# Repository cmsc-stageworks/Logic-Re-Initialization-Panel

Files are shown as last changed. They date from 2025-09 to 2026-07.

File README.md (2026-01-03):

# Logic Initialization Panel

Created by the BYU IEEE Branch for the CMSC

## Overview
The idea is that you take an isolinear chip that is "broken" and you place it in to have a certain logic circuit "fixed/repaired" the screen gives you a guide to be able to solve the puzzle/prompt. you then "write" it to the card

### Puzzle setup
The puzzle would consist of a series of (up to) 4 inputs and (up to) 4 outputs. These inputs could be things such as "Engine overheating" or "Autorization level 4 is given" or "Fire detected". The outputs could be "Turn on cooling fans" or "Override safety protocols" or "open airlock" etc. The user would be responsible for implemmenting the logic necessary to solve the puzzle at hand. 

### Interactivity
The user can test inputs manually by pressing the 4 buttons off to the input side of the logic panel, turning them on or off (true or false). They can then visually see how the logic would travel step by step in their current circuit.

### Completion
When they are ready to submit they hit the write button and it tests their circuit to verify correctness. If it is incorrect it throws an error and lets them try again. If it is correct it "writes" it to the card and they can move the card back to its original position to "fix" or "optimize" a system

## Learning outcomes
This panel teaches basic boolean logic (not, and, or) to children, or can be configured to challenge adults with more gates/configurations.

### Gate holder
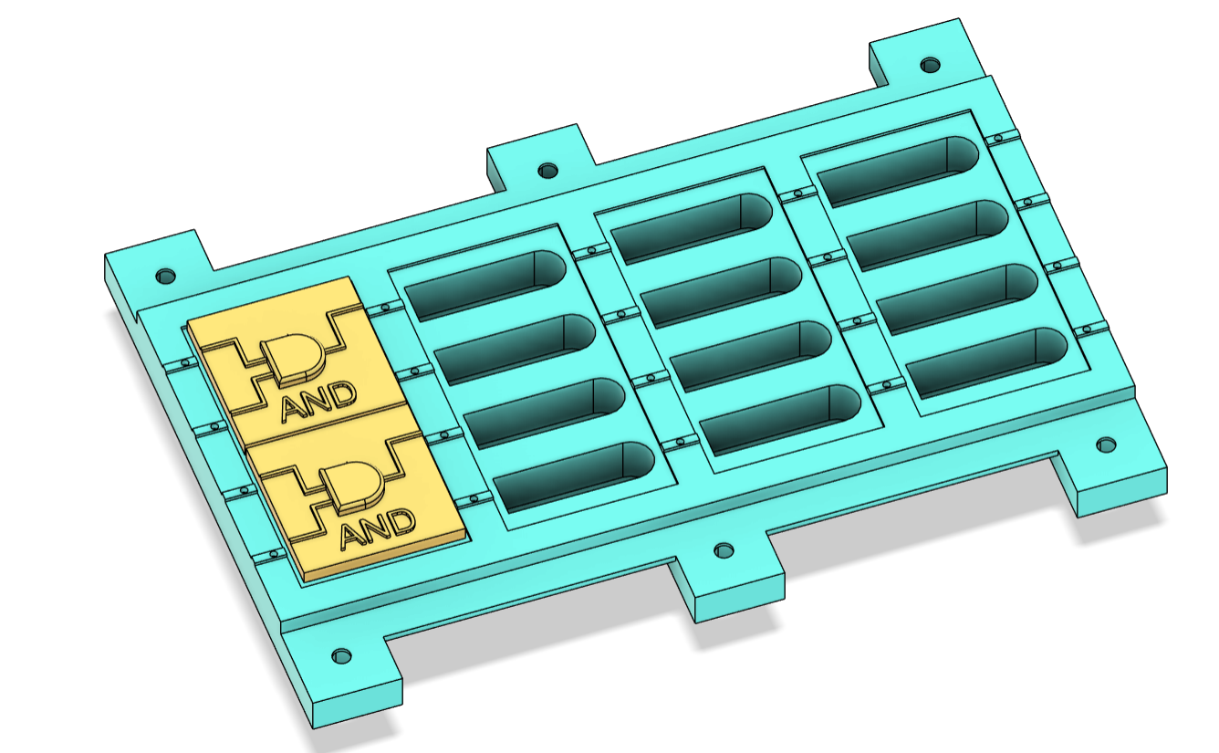
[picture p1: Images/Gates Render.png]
3d Render

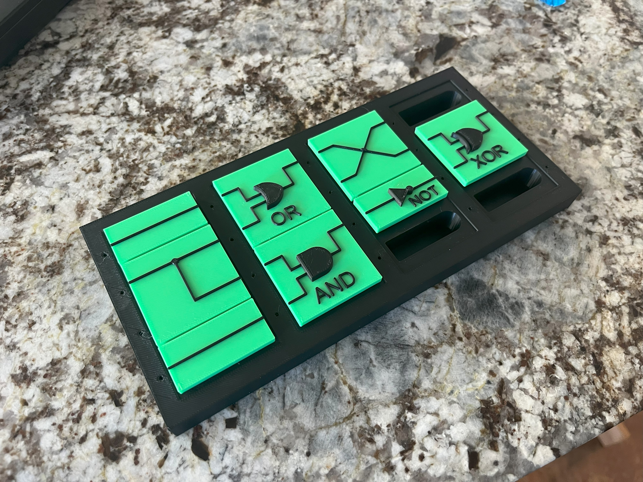
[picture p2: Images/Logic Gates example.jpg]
Example 1

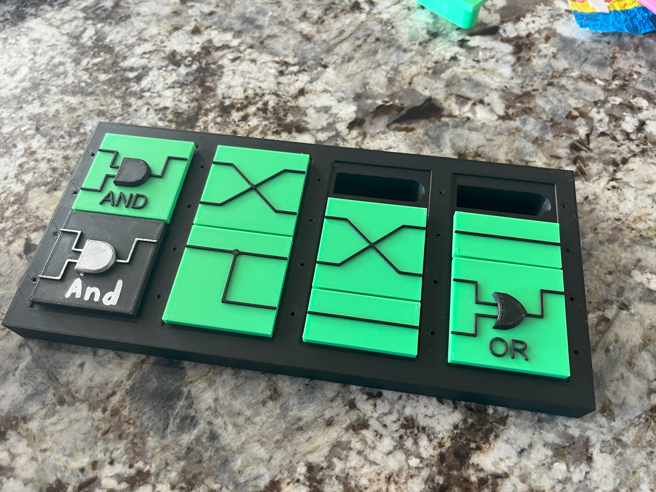
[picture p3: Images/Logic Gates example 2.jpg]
Example 2


### Initial Concept
Will be cut down, since this was originally started as a whole panel idea and was cut down to be a sub-panel.
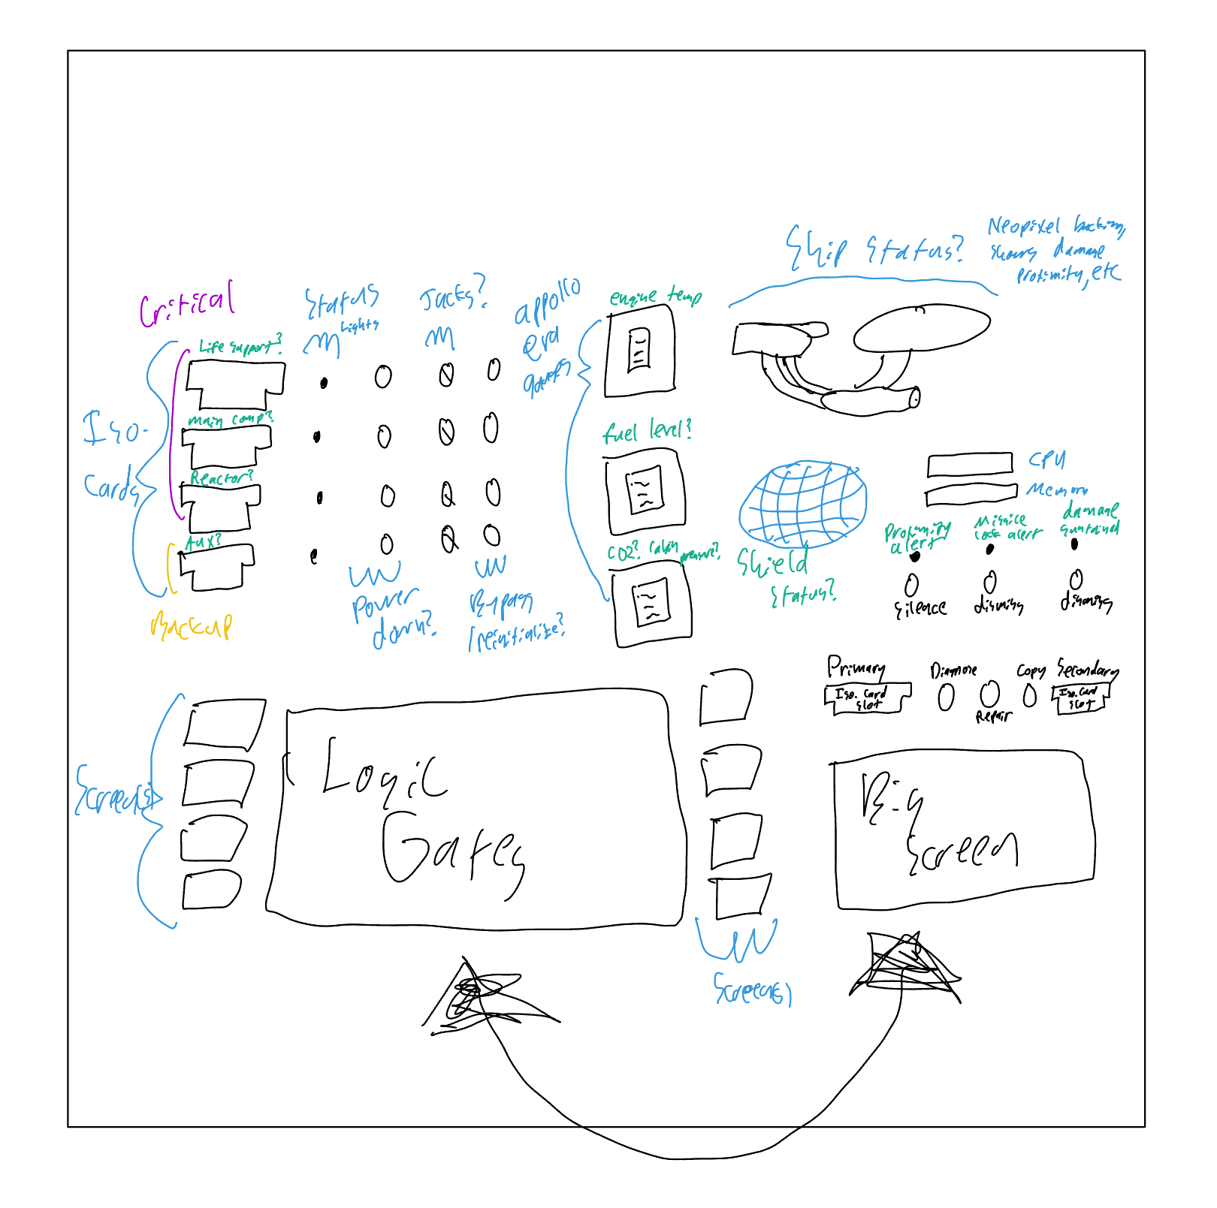
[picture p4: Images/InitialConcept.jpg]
Initial Concept

### Magnet Codes:
[logic_puzzle_addresses.txt](logic_puzzle_addresses.txt)
### File system
[Proposed File System](FileSystem.md)

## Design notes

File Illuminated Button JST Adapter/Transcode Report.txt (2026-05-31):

   ---- Transcoding 'C:\Users\swimn\AppData\Local\Temp\PentaLogix\ImportZip\cd4ad1d6-2cfa-49d5-bedc-17cfcb6de3c1\Illuminated Button JST Adapter-F_Mask.gbr' ----   Mon May 18 17:09:53 2026

D10   --> D100
D11   --> D101
D12   --> D102
D13   --> D103
-----------------------------------------------------------------

   ---- Transcoding 'C:\Users\swimn\AppData\Local\Temp\PentaLogix\ImportZip\cd4ad1d6-2cfa-49d5-bedc-17cfcb6de3c1\Illuminated Button JST Adapter-F_Cu.gbr' ----   Mon May 18 17:09:53 2026

D10   --> D104
D11   --> D105
D12   --> D106
D13   --> D107
D14   --> D108
-----------------------------------------------------------------

   ---- Transcoding 'C:\Users\swimn\AppData\Local\Temp\PentaLogix\ImportZip\cd4ad1d6-2cfa-49d5-bedc-17cfcb6de3c1\Illuminated Button JST Adapter-B_Cu.gbr' ----   Mon May 18 17:09:53 2026

D10   --> D109
D11   --> D110
D12   --> D111
D13   --> D112
D14   --> D113
-----------------------------------------------------------------

   ---- Transcoding 'C:\Users\swimn\AppData\Local\Temp\PentaLogix\ImportZip\cd4ad1d6-2cfa-49d5-bedc-17cfcb6de3c1\Illuminated Button JST Adapter-B_Mask.gbr' ----   Mon May 18 17:09:53 2026

D10   --> D114
D11   --> D115
D12   --> D116
D13   --> D117
-----------------------------------------------------------------

   ---- Transcoding 'C:\Users\swimn\AppData\Local\Temp\PentaLogix\ImportZip\cd4ad1d6-2cfa-49d5-bedc-17cfcb6de3c1\Illuminated Button JST Adapter-B_Silkscreen.gbr' ----   Mon May 18 17:09:53 2026

D10   --> D118
-----------------------------------------------------------------

   ---- Transcoding 'C:\Users\swimn\AppData\Local\Temp\PentaLogix\ImportZip\cd4ad1d6-2cfa-49d5-bedc-17cfcb6de3c1\Illuminated Button JST Adapter-Edge_Cuts.gbr' ----   Mon May 18 17:09:53 2026

D10   --> D119
-----------------------------------------------------------------

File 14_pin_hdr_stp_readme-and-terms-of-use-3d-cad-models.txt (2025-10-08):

EN   Your download at 10/03/2025 on PARTcommunity/PARTserver/3Dfindit.com:

       Dear user,
       
       attached please find the following file of our 3D CAD download portal PARTcommunity/PARTserver/3Dfindit.com powered by CADENAS:

       STEP, SSW-114-01-G-S-LL, SSW-114-01-G-S-LL.stp
	
       Information for use:

       The attached file was compressed ("ZIP"), in order to ensure a faster download.
       In order to unpack the file you need a special decompressing software. 

       If you do not have a decompressing software installed, you can download it using one of the following links:
       7Zip® (https://7-zip.de) or WinZip® (https://www.winzip.com)

       Please also check terms of use at https://www.cadenas.de/terms-of-use-3d-cad-models

       This is an automatically generated email from a system email address – please do not respond to it. If you have any questions, please feel free to contact the support directly.

       Best regards

       Your CADENAS GmbH
       support@cadenas.de

       >> 3DfindIT <<
       
       3DfindIT.com is the next dimension visual search engine that crawls billions 
       of 3D CAD & BIM models in hundreds of manufacturer catalogs available worldwide. 
       With intelligent search functions such as 3D shape search, 2D sketch & photo search 
       and parametric text & value input, 3DfindIT.com is the indispensable platform 
       for architects, planners, engineers and designers.

       >> Free APP for 3D CAD models <<
       
       Mobile access to 3D CAD models with your Smartphone or Tablet PC. 
       
       Download now at http://www.cadenas.de/en/app-store

       >> PARTcommunity - The network and information platform for engineers <<
       
       ■ Examples of use and ideas for components 
       ■ Information and experience exchange with other engineers

       Join the discussion now at http://www.partcommunity.com

       >> PARTsolutions - Find & manage standard, purchased, and own parts <<

       Reduce total product costs up to 70% in the development phase?

       In many companies PARTsolutions is one of the leading software systems helping
       engineers and purchasers to manage and find company-, supplier- and standard parts:

       ■ PURCHINEERING: Optimize cooperation of Purchasing and Engineering
       ■ Semiautomatic classification and intelligent search methods
       ■ Open for all systems such as PLM and ERP

       More information at http://www.cadenas.de/strategic-partsmanagement

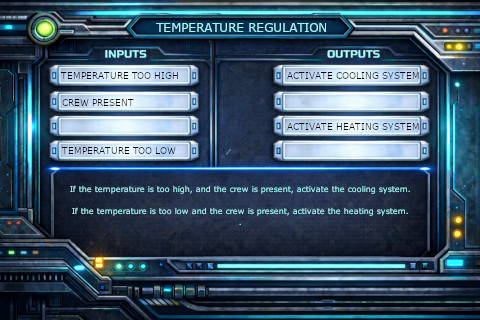
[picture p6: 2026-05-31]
Mainboard SD Example/Puzzles/TEMP_CONTROL/prompt.bmp

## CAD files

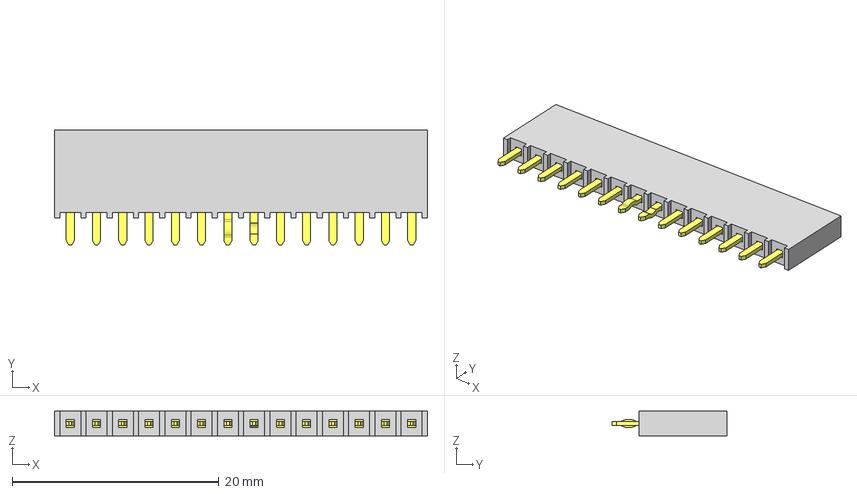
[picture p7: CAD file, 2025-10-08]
14 pin female header.stp
36.1 x 11.2 x 2.41 mm
T1SSW-114-01-G-S-LL
P2SSW-114-01-G-S-LL

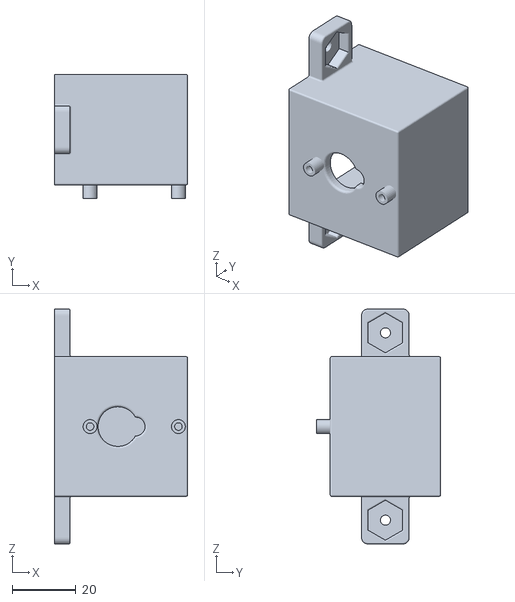
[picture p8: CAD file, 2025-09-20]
3D Models/Apollo Gauge/Back Body.stl
42.0 x 39.1 x 74.0

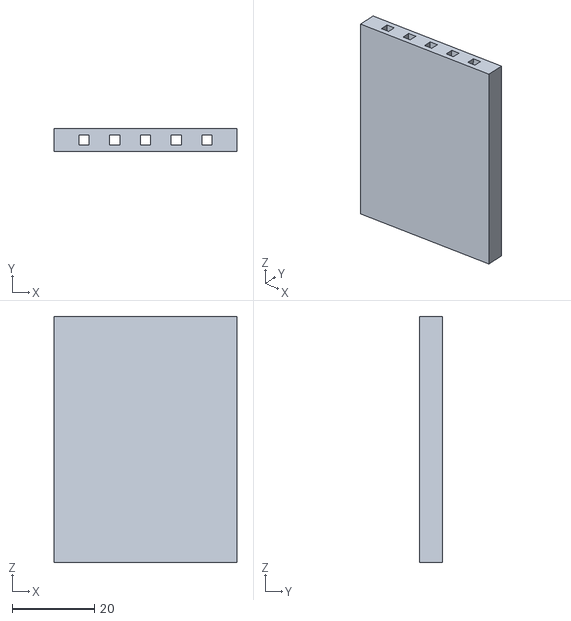
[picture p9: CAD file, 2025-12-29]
3D Models/Isolinear Chips NFC/Iso Card Body V2.stl
44.6 x 5.60 x 60.0

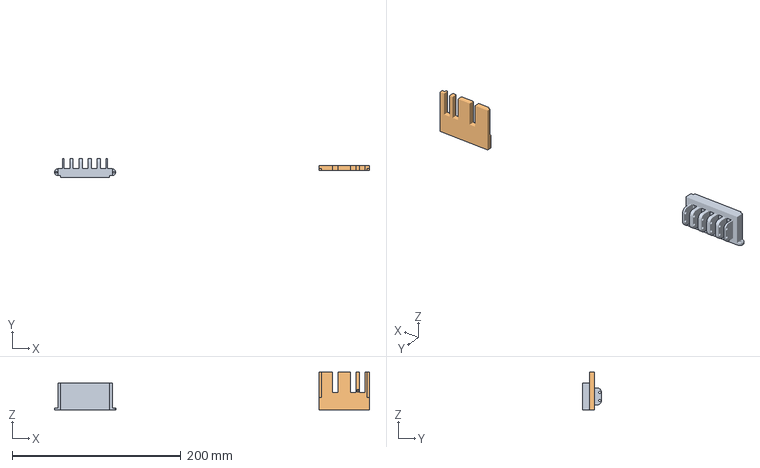
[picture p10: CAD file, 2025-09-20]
3D Models/Isolinear Chips/Print Profiles.3mf
373.3 x 22.3 x 44.8 mm
Isolinear Chip back.stl
Card Test.stl

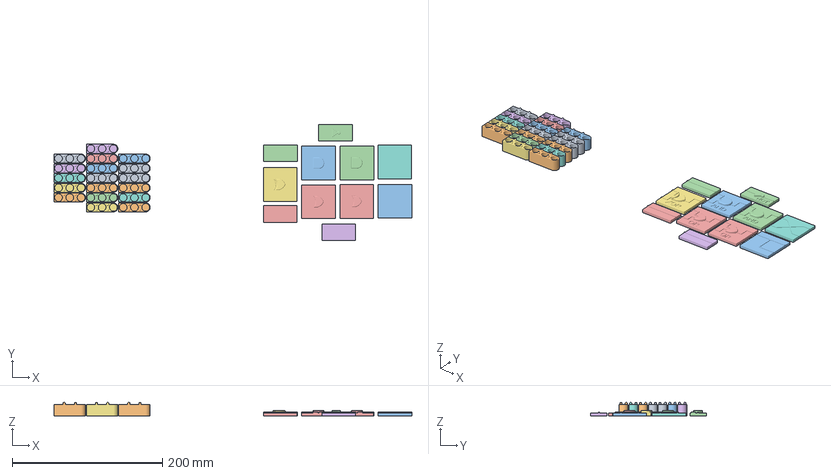
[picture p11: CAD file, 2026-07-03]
3D Models/Logic Panel/Logic Test Package.3mf
476.2 x 154.0 x 18.0 mm
Magnet Holder.stl x 18
And Gate.stl x 2
Not Gate.stl
Or Gate.stl x 2
Wire.stl x 3
XOR Gate.stl
Criss-Cross.stl
Splitter.stl

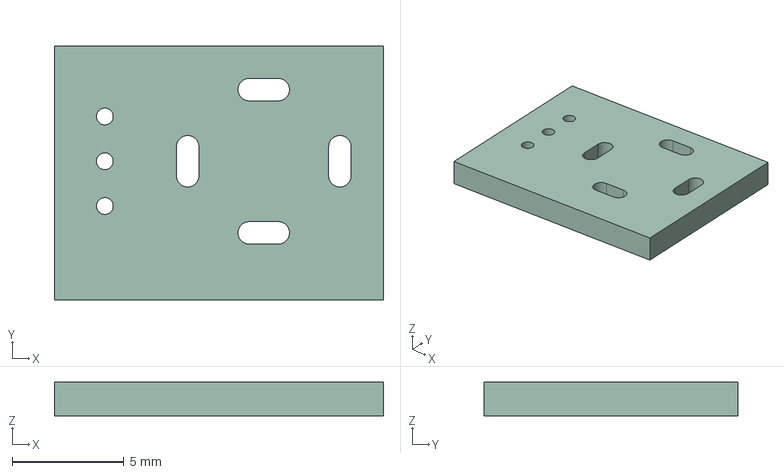
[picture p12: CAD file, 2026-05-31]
Illuminated Button Holder/Illuminated Button Holder.step
14.7 x 11.3 x 1.51 mm

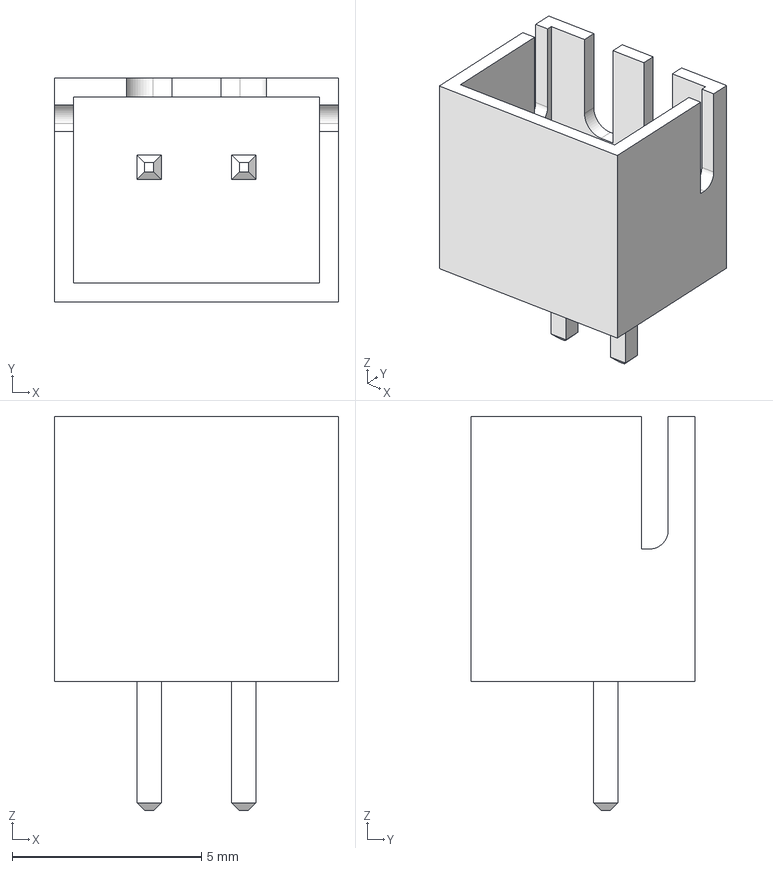
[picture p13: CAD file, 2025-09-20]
Isolinear Chip Board/Isolinear Board PCB/Connectors_JST.pretty-master/JST B2B-XH-A Through-hole shrouded header top entry type.step
7.50 x 5.90 x 10.4 mm

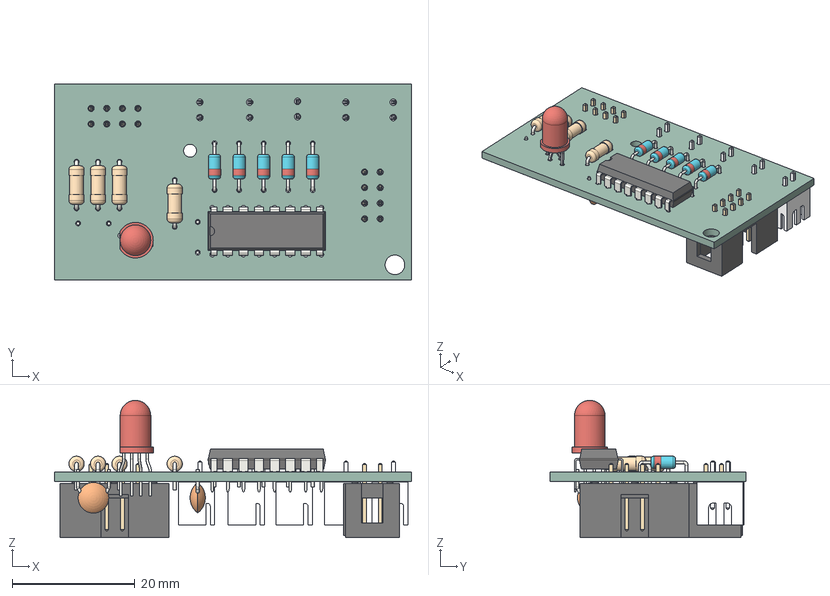
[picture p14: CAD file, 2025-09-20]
Isolinear Chip Board/Isolinear Board PCB/Isolinear Board PCB.step
58.2 x 32.0 x 22.4 mm
R_Axial_DIN0207_L6.3mm_D2.5mm_P7.62mm_Horizontal x 4
LED_D5.0mm-4_RGB_Staggered_Pins
D_DO-35_SOD27_P7.62mm_Horizontal x 5
DIP-16_W7.62mm
IDC-Header_2x04_P2.54mm_Vertical x 2
JST B2B-XH-A Through-hole shrouded header top entry type x 5
C_Disc_D5.0mm_W2.5mm_P5.00mm x 2
Isolinear Board PCB_PCB

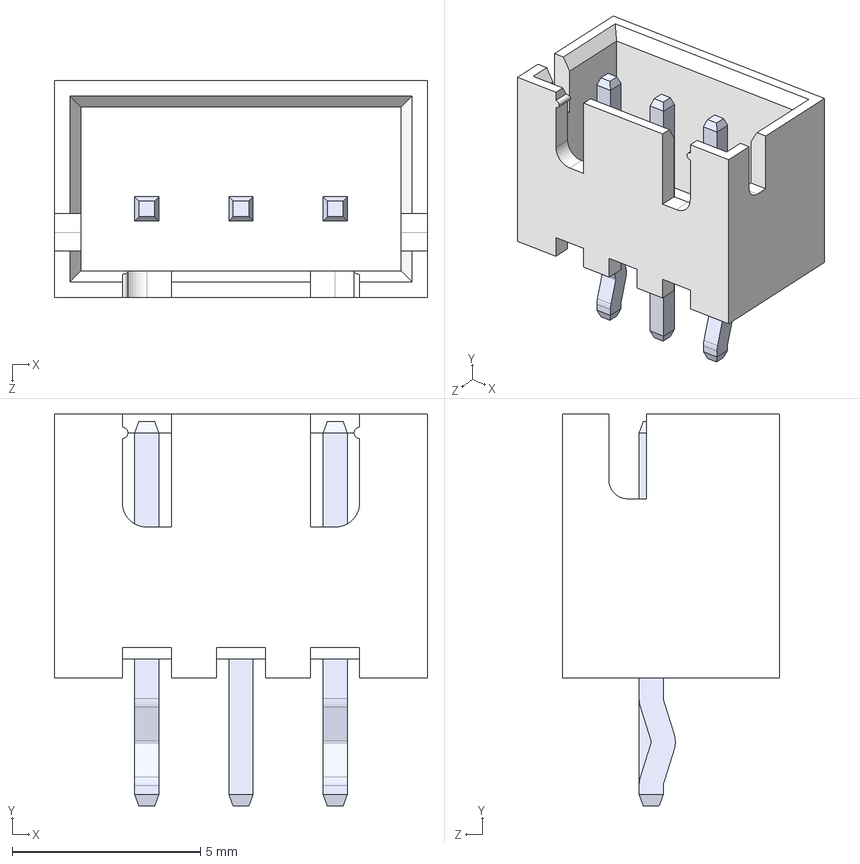
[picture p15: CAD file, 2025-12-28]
Isolinear Chip Board/LED Holder Iso Cards/3D Models/B3B-XH-A.STEP
9.90 x 10.4 x 5.75 mm

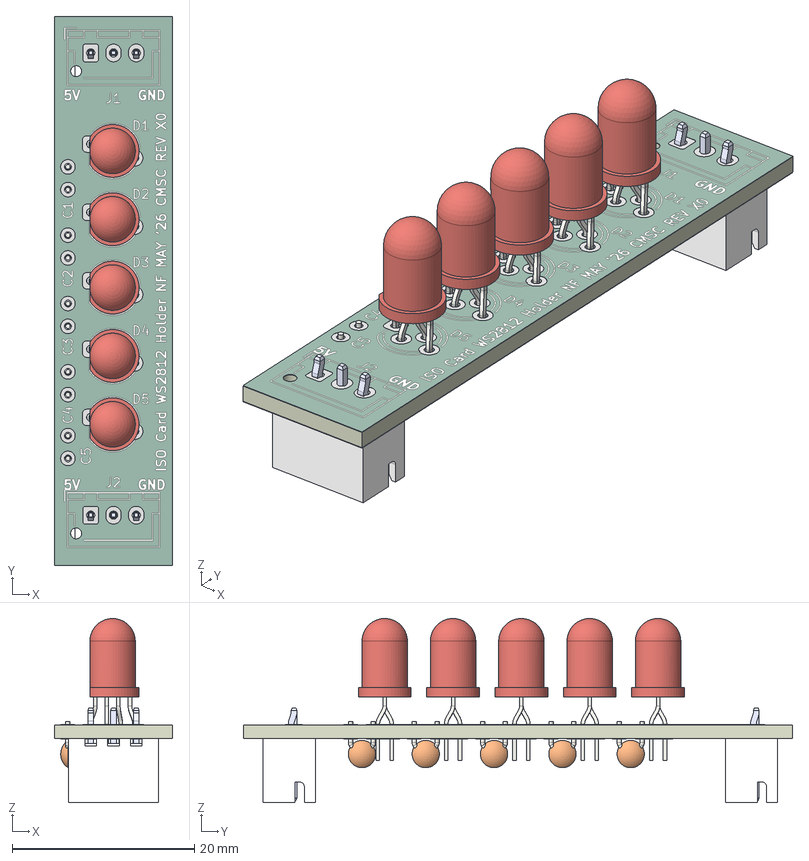
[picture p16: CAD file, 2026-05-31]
Isolinear Chip Board/LED Holder Iso Cards/LED Holder Iso Cards.step
13.0 x 60.2 x 20.2 mm
LED_D5.0mm-4_RGB_Staggered_Pins x 5
BxB-XH-A_03 x 2
C_Disc_D3.0mm_W1.6mm_P2.50mm x 5
LED Holder Iso Cards_copper
LED Holder Iso Cards_pad
LED Holder Iso Cards_silkscreen x 2
LED Holder Iso Cards_soldermask x 2
LED Holder Iso Cards_PCB

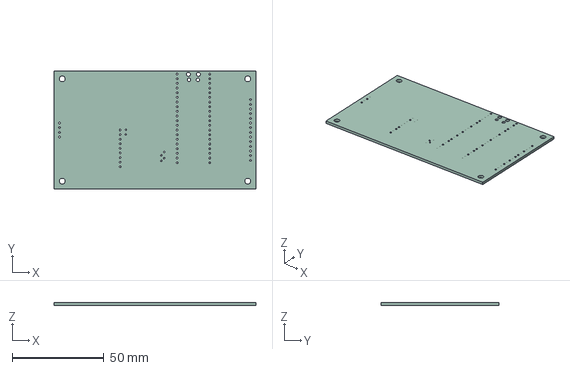
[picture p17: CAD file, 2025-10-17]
LCD daughter board/LCD_Daughter/LCD_Daughter.step
110.0 x 64.0 x 1.51 mm

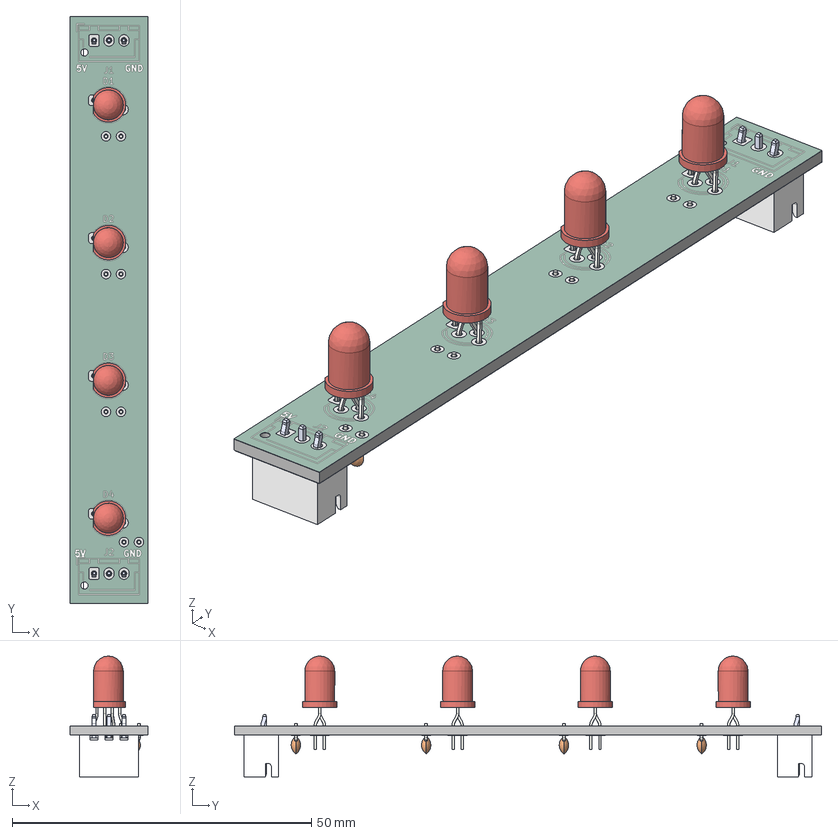
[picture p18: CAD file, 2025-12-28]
Logic Gates/LED Holder Logic Gates/LED Holder Logic Gates.step
13.0 x 98.0 x 20.2 mm
LED_D5.0mm-4_RGB_Staggered_Pins x 4
BxB-XH-A_03 x 2
C_Disc_D3.0mm_W1.6mm_P2.50mm x 4
LED Holder Logic Gates_copper
LED Holder Logic Gates_pad
LED Holder Logic Gates_silkscreen
LED Holder Logic Gates_soldermask
LED Holder Logic Gates_PCB

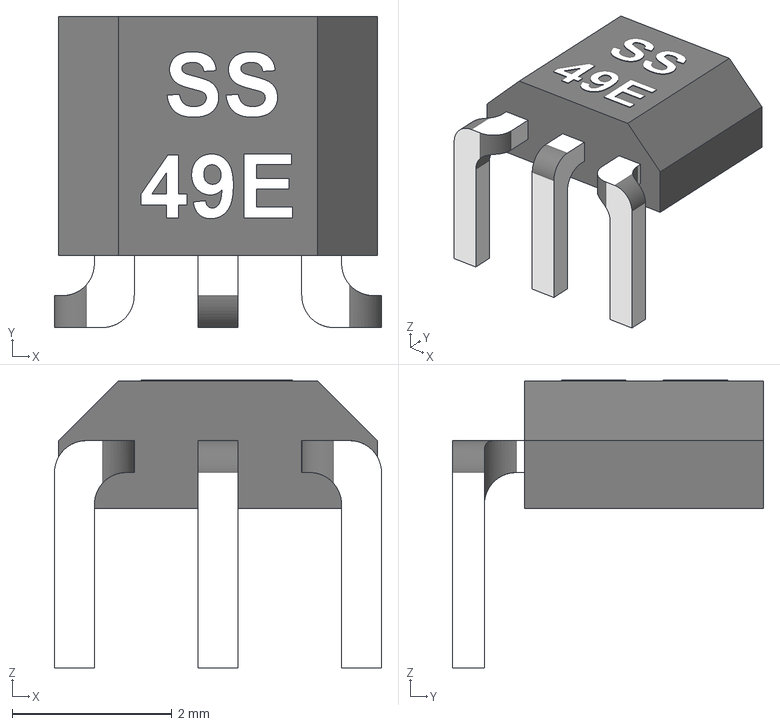
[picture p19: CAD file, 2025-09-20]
Logic Gates/Logic board magnetic sensor/SS49E 90 degree bend.step
4.10 x 3.90 x 3.61 mm

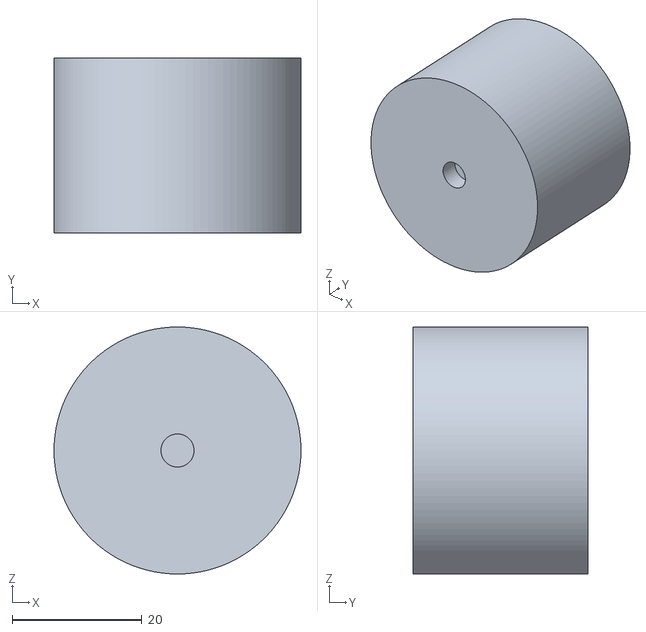
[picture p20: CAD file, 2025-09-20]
3D Models/Apollo Gauge/Gauge Drum.stl
38.0 x 27.0 x 38.0

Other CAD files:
3D Models/Isolinear Chips NFC/Iso Card Diffuser V2.stl
3D Models/Isolinear Chips/PCB REV1.stl
3D Models/Logic Panel/Splitter.stl
3D Models/Isolinear Chips NFC/Card Holder.stl
3D Models/Isolinear Chips NFC/Clip.stl
3D Models/Isolinear Chips NFC/Iso Card Body.stl
3D Models/Isolinear Chips NFC/Iso Card Diffuser.stl
3D Models/Isolinear Chips NFC/Iso Card Print Profile.3mf
3D Models/Isolinear Chips/Card Bare Minimum.stl
3D Models/Isolinear Chips/Card Test.stl
3D Models/Isolinear Chips/Isolinear Chip back V2.stl
3D Models/Isolinear Chips/Isolinear Chip back.stl
3D Models/Isolinear Chips/Peg.stl
3D Models/Isolinear Chips/Washer.stl
3D Models/Logic Panel/And Gate.stl
3D Models/Logic Panel/Criss-Cross.stl
3D Models/Logic Panel/Logic puzzle board.stl
3D Models/Logic Panel/Magnet Holder.stl
3D Models/Logic Panel/Not Gate.stl
3D Models/Logic Panel/Or Gate.stl
3D Models/Logic Panel/Wire.stl
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

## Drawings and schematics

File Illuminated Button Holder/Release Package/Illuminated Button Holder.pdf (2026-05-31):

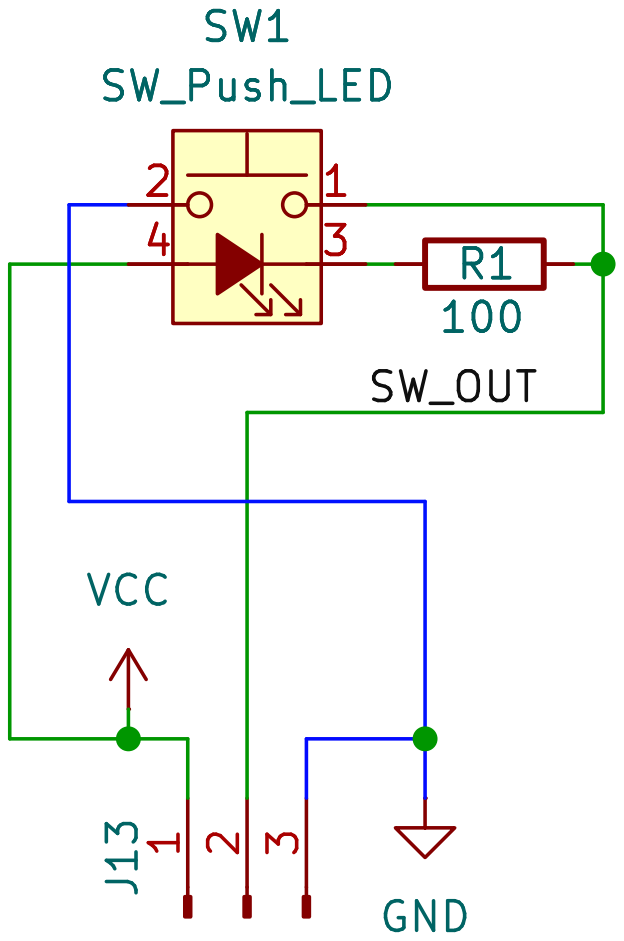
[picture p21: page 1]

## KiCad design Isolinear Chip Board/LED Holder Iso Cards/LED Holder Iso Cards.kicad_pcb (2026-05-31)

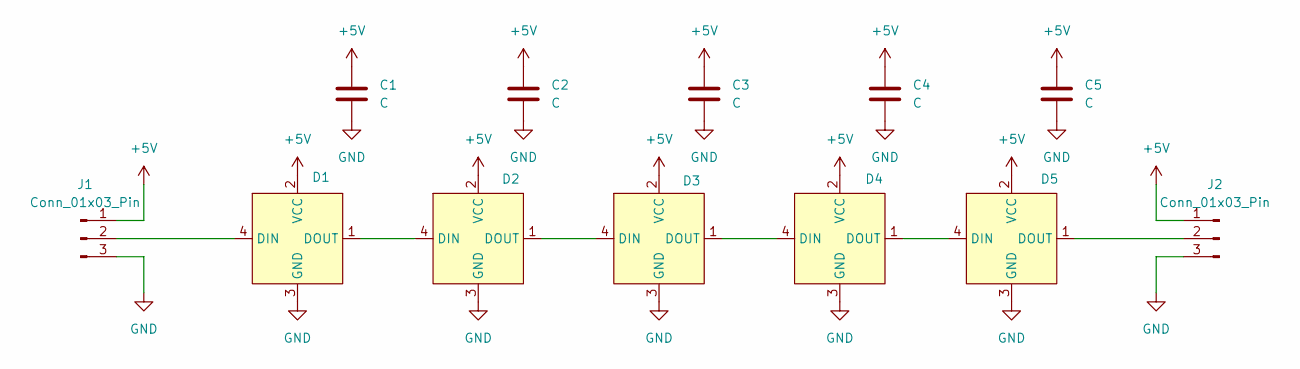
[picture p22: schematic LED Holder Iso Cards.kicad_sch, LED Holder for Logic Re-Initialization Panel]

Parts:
C1, C2, C3, C4, C5: C; C_Disc_D3.0mm_W1.6mm_P2.50mm
D1, D2, D3, D4, D5: NeoPixel_THT; LED_D5.0mm-4_RGB_Staggered_Pins
J1, J2: Conn_01x03_Pin; JST_XH_B3B-XH-AM_1x03_P2.50mm_Vertical

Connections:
+5V: C1.1, C2.1, C3.1, C4.1, C5.1, D1.2 (VCC), D2.2 (VCC), D3.2 (VCC), D4.2 (VCC), D5.2 (VCC), J1.1, J2.1
GND: C1.2, C2.2, C3.2, C4.2, C5.2, D1.3 (GND), D2.3 (GND), D3.3 (GND), D4.3 (GND), D5.3 (GND), J1.3, J2.3
unnamed: D1.4 (DIN), J1.2
unnamed: D1.1 (DOUT), D2.4 (DIN)
unnamed: D2.1 (DOUT), D3.4 (DIN)
unnamed: D3.1 (DOUT), D4.4 (DIN)
unnamed: D4.1 (DOUT), D5.4 (DIN)
unnamed: D5.1 (DOUT), J2.2

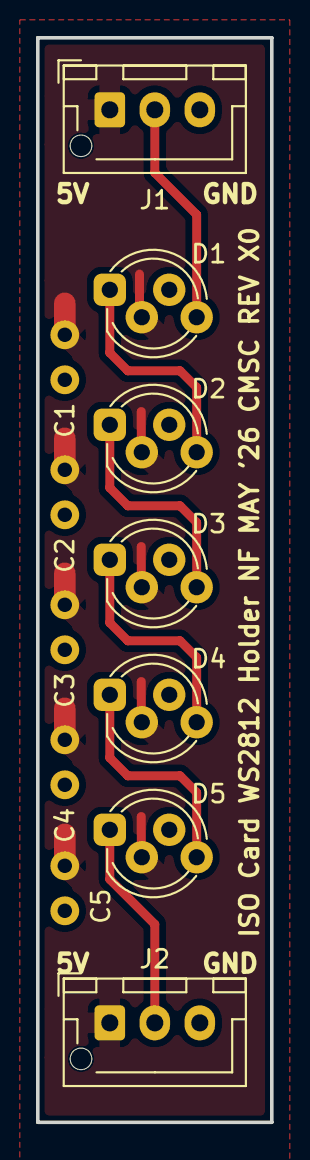
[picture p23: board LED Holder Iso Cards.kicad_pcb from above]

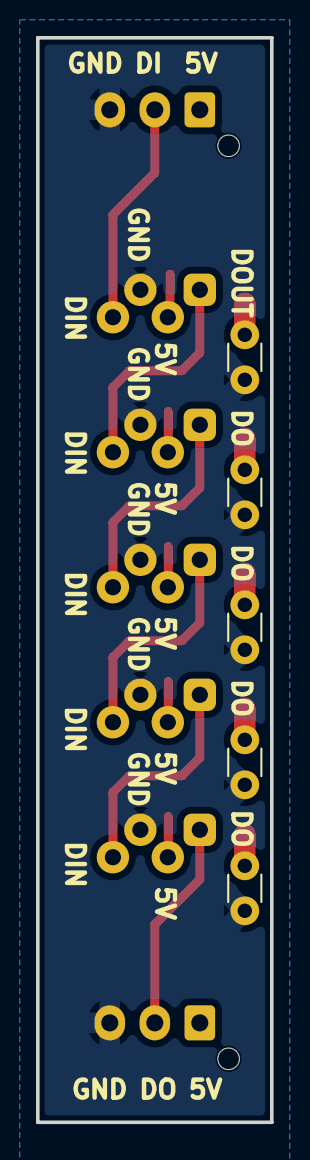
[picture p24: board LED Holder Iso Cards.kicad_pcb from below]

Board: 2 copper layers, 13.0 x 60.2 mm, 12 parts (5 on the bottom side), 8 nets.

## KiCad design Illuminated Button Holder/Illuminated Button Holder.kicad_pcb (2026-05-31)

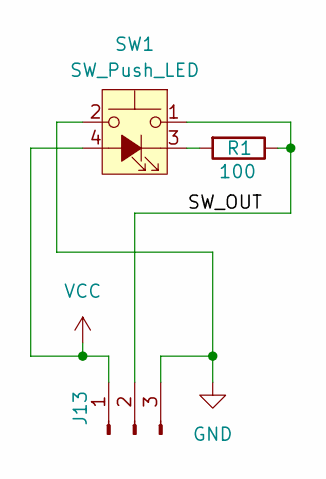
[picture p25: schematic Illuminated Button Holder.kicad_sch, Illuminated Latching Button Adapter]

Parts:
J13: Conn_01x03_Pin; JST_PH_B3B-PH-K_1x03_P2.00mm_Vertical
R1: 100; R_0805_2012Metric_Pad1.20x1.40mm_HandSolder
SW1: SW_Push_LED; Pushbutton

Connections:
/SW_OUT: J13.2, R1.1, SW1.1
GND: J13.3, SW1.2
unnamed: R1.2, SW1.3 (K)
VCC: J13.1, SW1.4 (A)

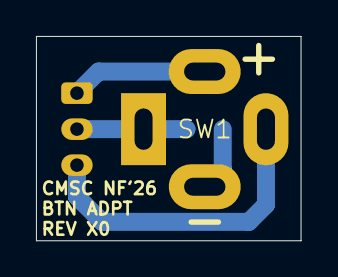
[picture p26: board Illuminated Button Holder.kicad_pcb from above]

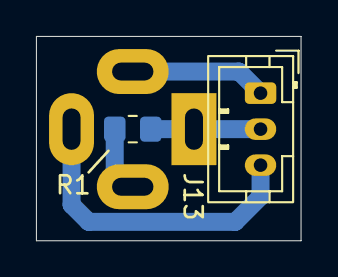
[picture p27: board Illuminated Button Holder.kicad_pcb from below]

Board: 2 copper layers, 14.7 x 11.4 mm, 3 parts (2 on the bottom side), 4 nets.

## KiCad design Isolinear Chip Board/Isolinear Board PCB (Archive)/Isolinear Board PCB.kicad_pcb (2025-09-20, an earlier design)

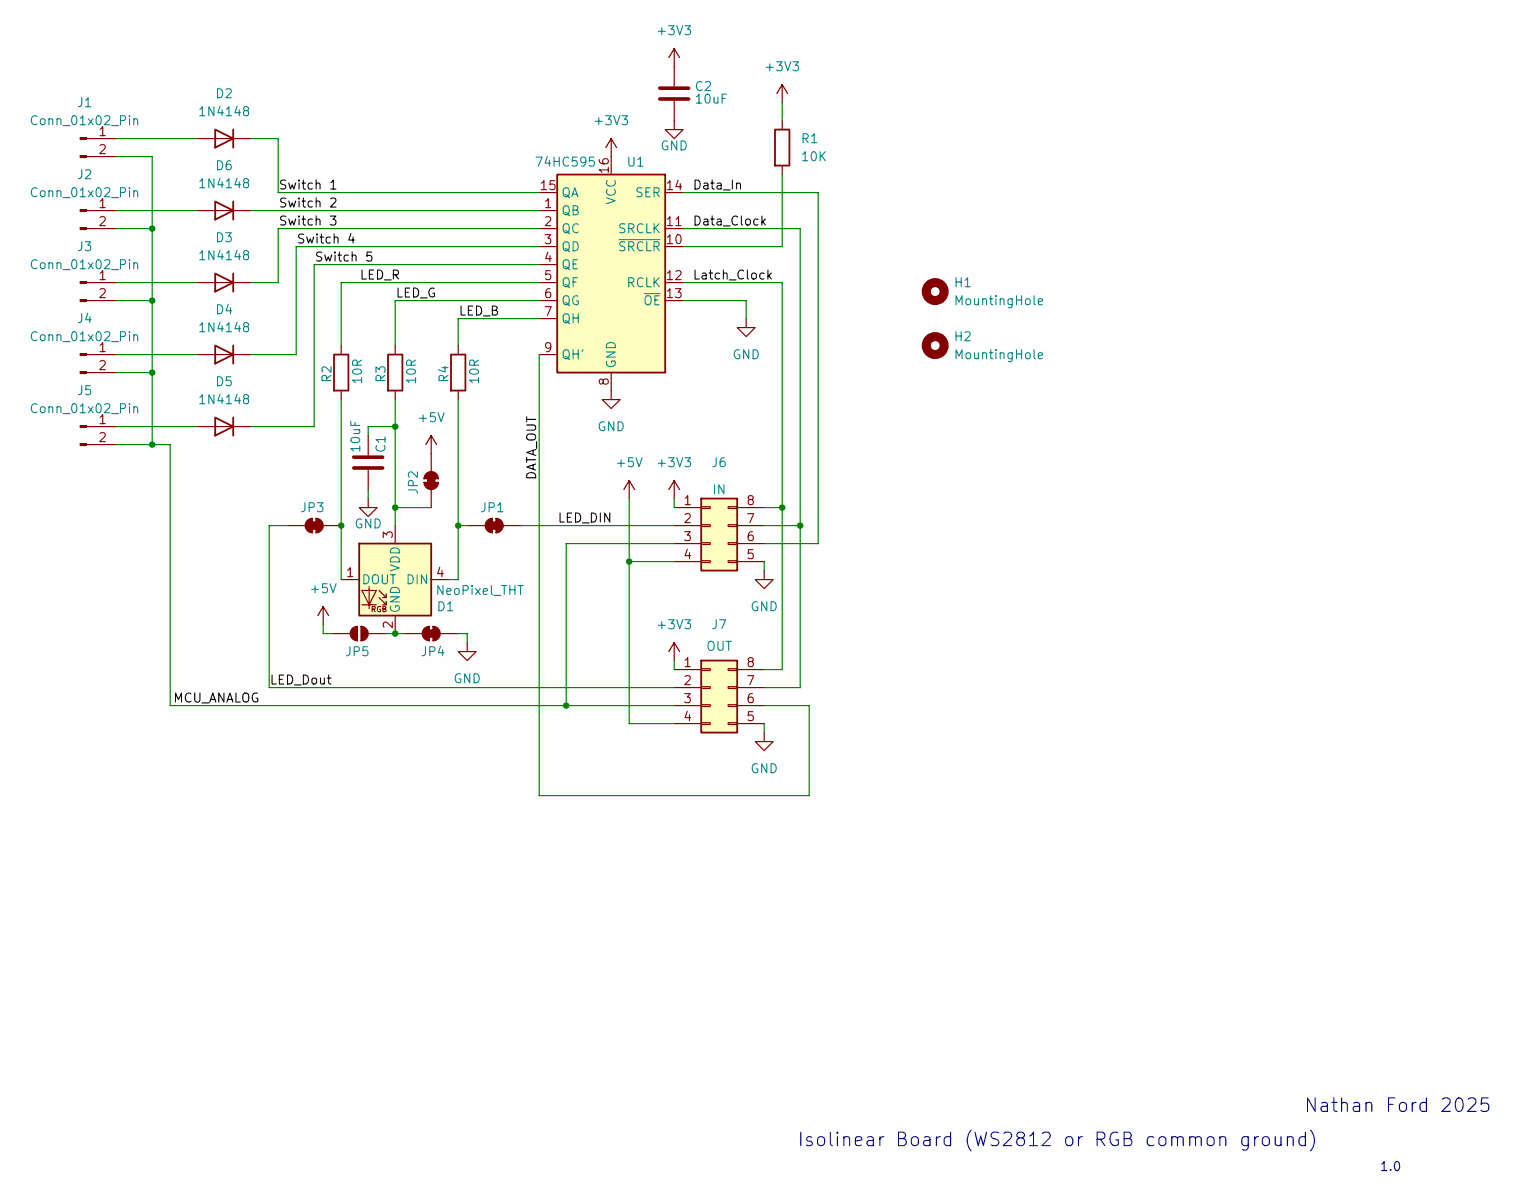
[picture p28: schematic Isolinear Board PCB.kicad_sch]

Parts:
C1, C2: 10uF; C_Disc_D5.0mm_W2.5mm_P5.00mm
D1: NeoPixel_THT; LED_D5.0mm-4_RGB_Staggered_Pins
D2, D3, D4, D5, D6: 1N4148; D_DO-35_SOD27_P7.62mm_Horizontal
H1: MountingHole; MountingHole_3.2mm_M3
H2: MountingHole; MountingHole_2.1mm
J1, J2, J3, J4, J5: Conn_01x02_Pin; JST_XH_B02B-XH-A_02x2.50mm_Straight
J6: IN; IDC-Header_2x04_P2.54mm_Vertical
J7: OUT; IDC-Header_2x04_P2.54mm_Vertical
JP1, JP2, JP3, JP4: SolderJumper_2_Bridged; SolderJumper-2_P1.3mm_Bridged2Bar_RoundedPad1.0x1.5mm
JP5: SolderJumper_2_Open; SolderJumper-2_P1.3mm_Open_RoundedPad1.0x1.5mm
R1: 10K; R_Axial_DIN0207_L6.3mm_D2.5mm_P7.62mm_Horizontal
R2, R3, R4: 10R; R_Axial_DIN0207_L6.3mm_D2.5mm_P7.62mm_Horizontal
U1: 74HC595; DIP-16_W7.62mm_LongPads

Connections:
+3V3: C2.1, J6.1, J7.1, R1.1, U1.16 (VCC)
+5V: J6.4, J7.4, JP2.2 (B), JP5.1 (A)
/DATA_OUT: J7.6, U1.9 (QH')
/Data_Clock: J6.7, J7.7, U1.11 (SRCLK)
/Data_In: J6.6, U1.14 (SER)
/LED_B: R4.1, U1.7 (QH)
/LED_DIN: J6.2, JP1.2 (B)
/LED_Dout: J7.2, JP3.1 (A)
/LED_G: R3.1, U1.6 (QG)
/LED_R: R2.1, U1.5 (QF)
/Latch_Clock: J6.8, J7.8, U1.12 (RCLK)
/MCU_ANALOG: J1.2, J2.2, J3.2, J4.2, J5.2, J6.3, J7.3
/Switch 1: D2.1 (K), U1.15 (QA)
/Switch 2: D6.1 (K), U1.1 (QB)
/Switch 3: D3.1 (K), U1.2 (QC)
/Switch 4: D4.1 (K), U1.3 (QD)
/Switch 5: D5.1 (K), U1.4 (QE)
GND: C1.2, C2.2, J6.5, J7.5, JP4.2 (B), U1.8 (GND), U1.13 (~OE)
unnamed: D1.4 (DIN), JP1.1 (A), R4.2
unnamed: D1.1 (DOUT), JP3.2 (B), R2.2
unnamed: D1.2 (GND), JP4.1 (A), JP5.2 (B)
unnamed: C1.1, D1.3 (VDD), JP2.1 (A), R3.2
unnamed: D2.2 (A), J1.1
unnamed: D3.2 (A), J3.1
unnamed: D4.2 (A), J4.1
unnamed: D5.2 (A), J5.1
unnamed: D6.2 (A), J2.1
unnamed: R1.2, U1.10 (~SRCLR)

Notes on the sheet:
Isolinear Board (WS2812 or RGB common ground)
1.0
Nathan Ford 2025

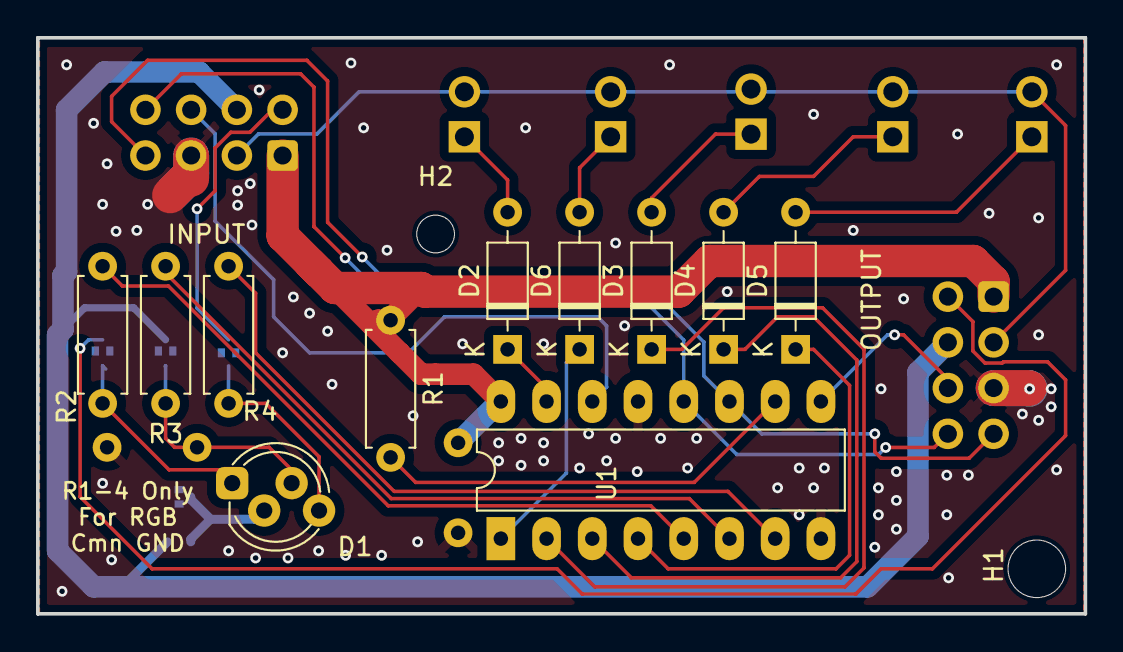
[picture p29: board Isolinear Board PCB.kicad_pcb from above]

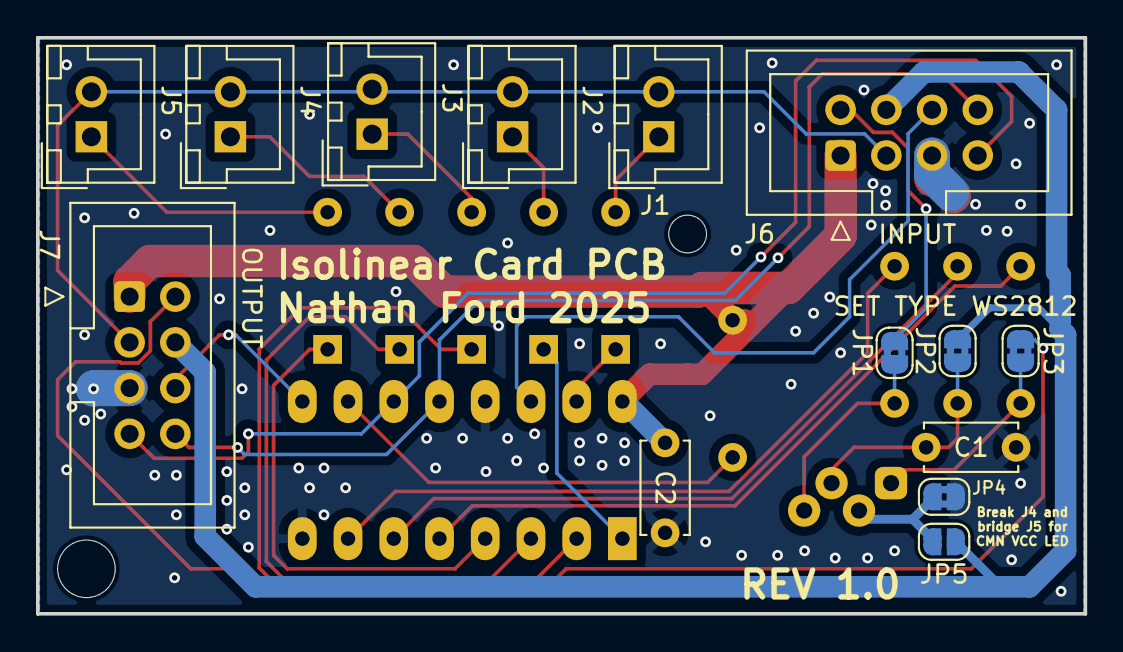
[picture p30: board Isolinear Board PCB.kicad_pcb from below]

Board: 2 copper layers, 58.2 x 32.0 mm, 27 parts (14 on the bottom side), 28 nets.

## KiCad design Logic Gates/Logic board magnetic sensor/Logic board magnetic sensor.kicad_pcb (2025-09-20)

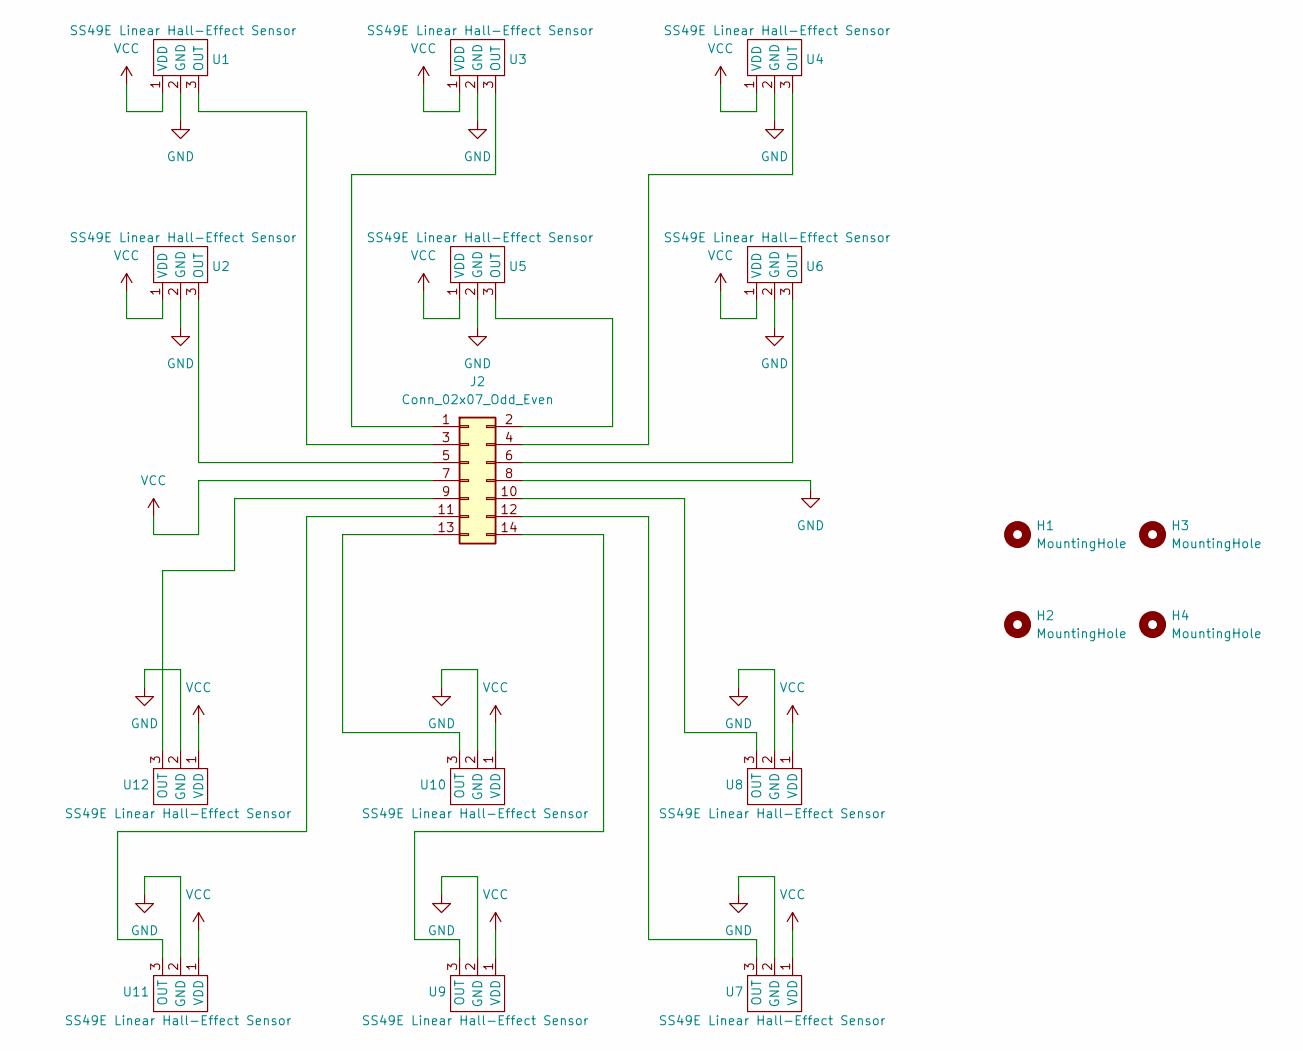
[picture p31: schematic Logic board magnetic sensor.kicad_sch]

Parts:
H1, H2, H3, H4: MountingHole; MountingHole_3.2mm_M3
J2: Conn_02x07_Odd_Even; IDC-Header_2x07_P2.54mm_Vertical
U1, U2, U3, U4, U5, U6, U7, U8, U9, U10, U11, U12: Linear Hall Effect Sensor SS49E

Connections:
GND: J2.8, U1.2 (GND), U2.2 (GND), U3.2 (GND), U4.2 (GND), U5.2 (GND), U6.2 (GND), U7.2 (GND), U8.2 (GND), U9.2 (GND), U10.2 (GND), U11.2 (GND), U12.2 (GND)
unnamed: J2.1, U3.3 (OUT)
unnamed: J2.2, U5.3 (OUT)
unnamed: J2.3, U1.3 (OUT)
unnamed: J2.4, U4.3 (OUT)
unnamed: J2.5, U2.3 (OUT)
unnamed: J2.6, U6.3 (OUT)
unnamed: J2.9, U12.3 (OUT)
unnamed: J2.10, U8.3 (OUT)
unnamed: J2.11, U11.3 (OUT)
unnamed: J2.12, U7.3 (OUT)
unnamed: J2.13, U10.3 (OUT)
unnamed: J2.14, U9.3 (OUT)
VCC: J2.7, U1.1 (VDD), U2.1 (VDD), U3.1 (VDD), U4.1 (VDD), U5.1 (VDD), U6.1 (VDD), U7.1 (VDD), U8.1 (VDD), U9.1 (VDD), U10.1 (VDD), U11.1 (VDD), U12.1 (VDD)

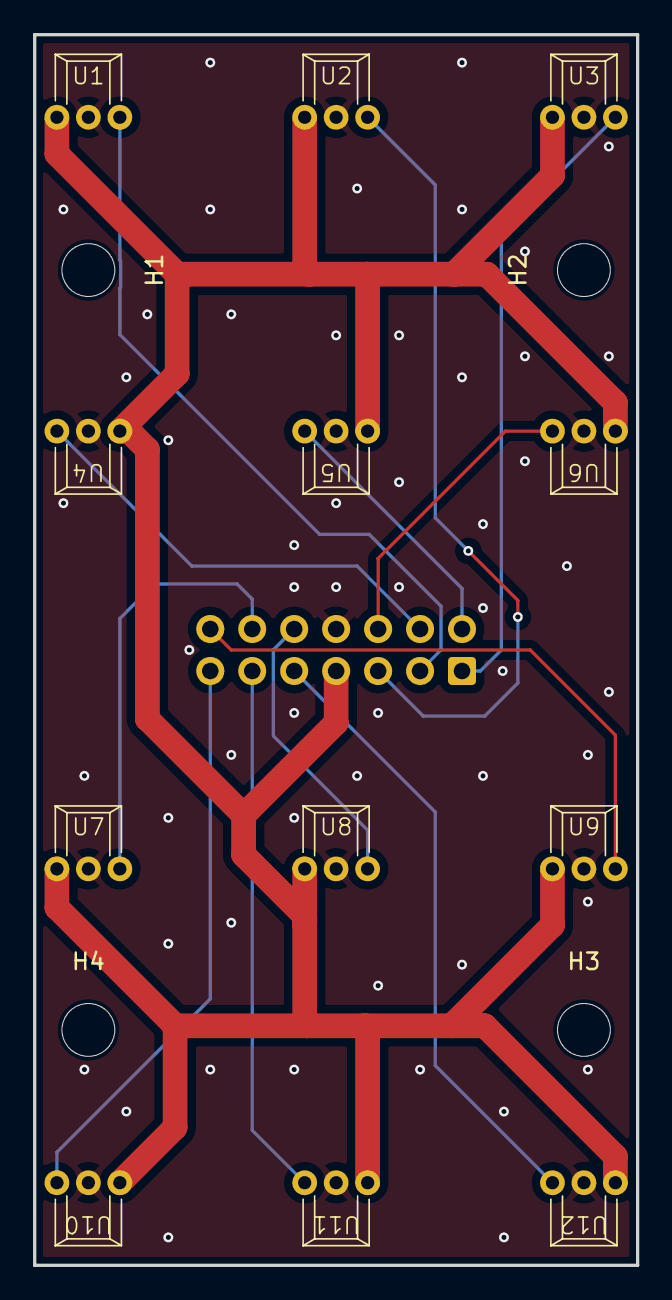
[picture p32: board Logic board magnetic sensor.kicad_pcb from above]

Board: 2 copper layers, 36.5 x 74.5 mm, 17 parts (1 on the bottom side), 14 nets.

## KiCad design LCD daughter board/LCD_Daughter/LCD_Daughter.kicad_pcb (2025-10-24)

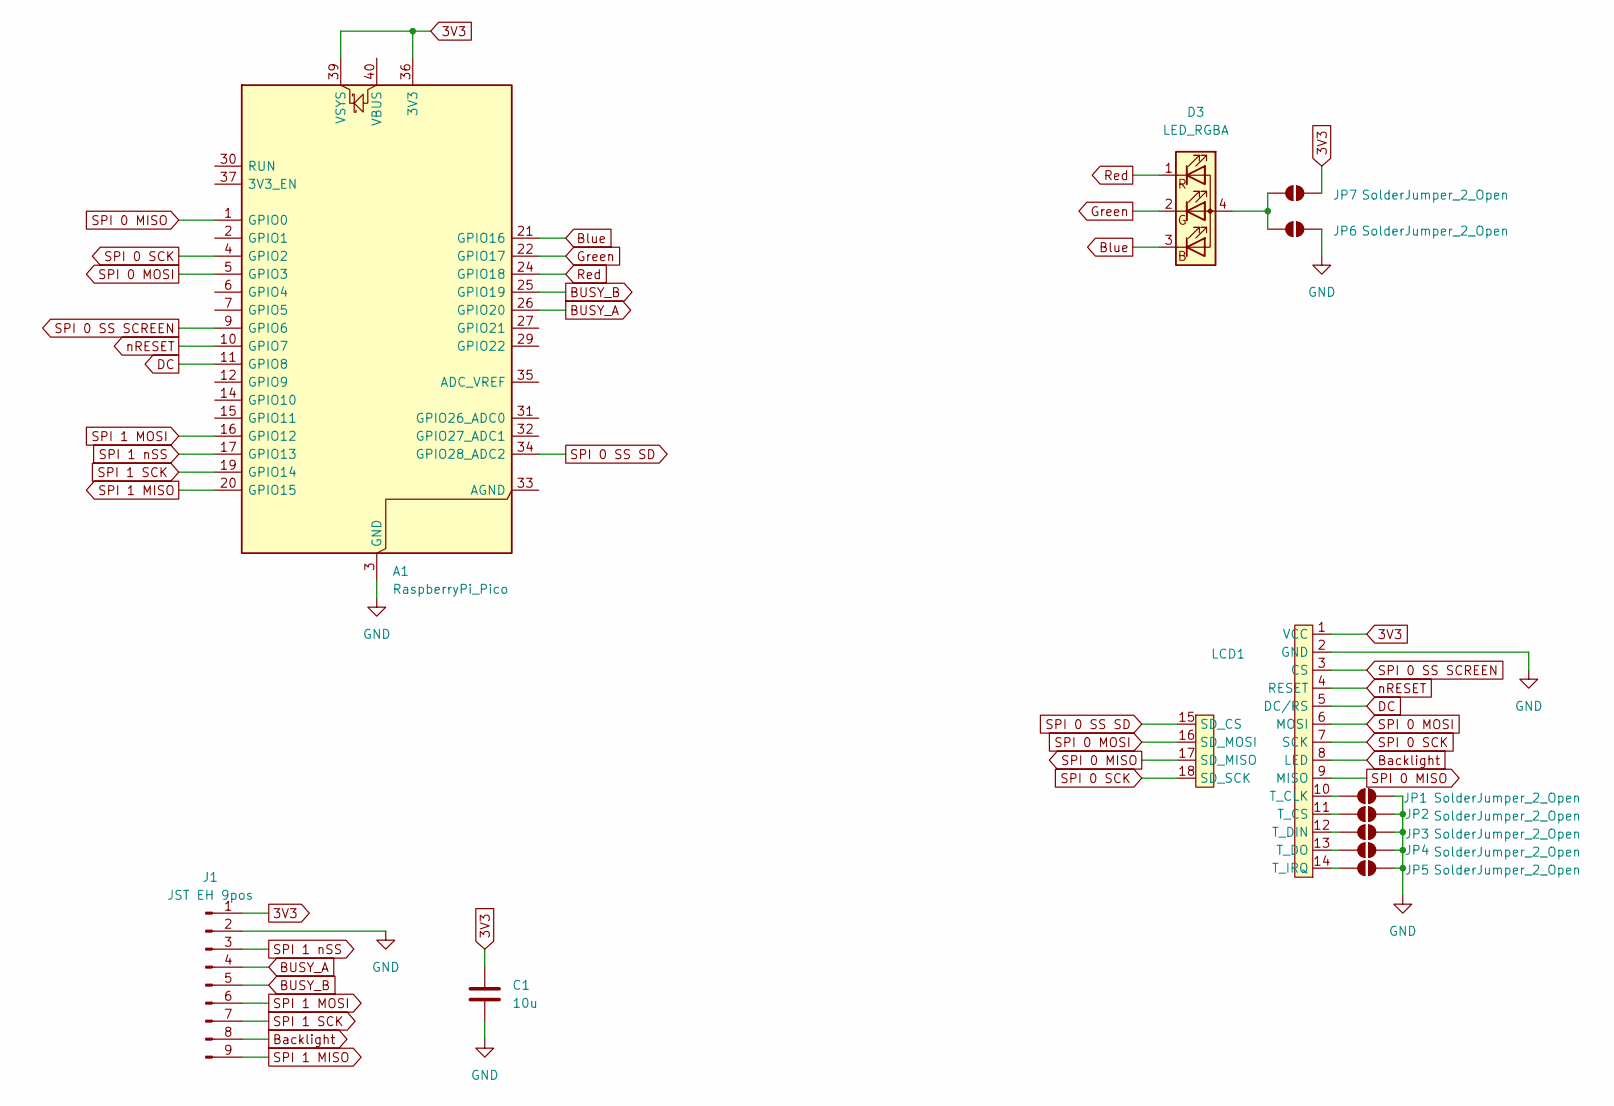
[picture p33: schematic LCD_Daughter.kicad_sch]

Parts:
A1: RaspberryPi_Pico; RaspberryPi_Pico_Common_Unspecified
C1: 10u; C_Disc_D3.0mm_W2.0mm_P2.50mm
D3: LED_RGBA; LED_D5.0mm-4_RGB_Staggered_Pins
J1: JST EH 9pos; JST_EH_B9B-EH-A_1x09_P2.50mm_Vertical
JP1, JP2, JP3, JP4, JP5, JP6, JP7: SolderJumper_2_Open; SolderJumper-2_P1.3mm_Open_TrianglePad1.0x1.5mm
LCD1: LCD

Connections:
3V3: A1.36 (3V3), A1.39 (VSYS), C1.1, J1.1, JP7.2 (B), LCD1.1 (VCC)
BUSY_A: A1.26 (GPIO20), J1.4
BUSY_B: A1.25 (GPIO19), J1.5
Backlight: J1.8, LCD1.8 (LED)
Blue: A1.21 (GPIO16), D3.3 (BK)
DC: A1.11 (GPIO8), LCD1.5 (DC/RS)
GND: A1.3 (GND), A1.8 (GND), A1.13 (GND), A1.18 (GND), A1.23 (GND), A1.28 (GND), A1.38 (GND), C1.2, J1.2, JP1.2 (B), JP2.2 (B), JP3.2 (B), JP4.2 (B), JP5.2 (B), JP6.2 (B), LCD1.2 (GND)
Green: A1.22 (GPIO17), D3.2 (GK)
unnamed: D3.4 (A), JP6.1 (A), JP7.1 (A)
unnamed: JP1.1 (A), LCD1.10 (T_CLK)
unnamed: JP2.1 (A), LCD1.11 (T_CS)
unnamed: JP3.1 (A), LCD1.12 (T_DIN)
unnamed: JP4.1 (A), LCD1.13 (T_DO)
unnamed: JP5.1 (A), LCD1.14 (T_IRQ)
Red: A1.24 (GPIO18), D3.1 (RK)
SPI 0 MISO: A1.1 (GPIO0), LCD1.9 (MISO), LCD1.17 (SD_MISO)
SPI 0 MOSI: A1.5 (GPIO3), LCD1.6 (MOSI), LCD1.16 (SD_MOSI)
SPI 0 SCK: A1.4 (GPIO2), LCD1.7 (SCK), LCD1.18 (SD_SCK)
SPI 0 SS SCREEN: A1.9 (GPIO6), LCD1.3 (CS)
SPI 0 SS SD: A1.34 (GPIO28_ADC2), LCD1.15 (SD_CS)
SPI 1 MISO: A1.20 (GPIO15), J1.9
SPI 1 MOSI: A1.16 (GPIO12), J1.6
SPI 1 SCK: A1.19 (GPIO14), J1.7
SPI 1 nSS: A1.17 (GPIO13), J1.3
nRESET: A1.10 (GPIO7), LCD1.4 (RESET)



Board: 2 copper layers, 110.0 x 64.0 mm, 12 parts (8 on the bottom side), 25 nets.

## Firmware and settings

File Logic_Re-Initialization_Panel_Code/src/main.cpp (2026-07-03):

#include "globalFlags.h"
// #include "freertos/FreeRTOS.h"
// #include "freertos/task.h"
// #include "esp_timer.h"
#include <Adafruit_NeoPixel.h>
#include <ESP32Servo.h>
#include <MainBoard.h>
#include <isoCards.h>
#include <Adafruit_GFX.h>
#include <Adafruit_ST7796S.h>
#include <esp_random.h>
#include <Wire.h>
#include <Ethernet3.h>
#include <SdFat.h>
#include "cardParser.h"
#include "Ethernet3.h"
#include <Adafruit_ILI9341.h>
#include <Adafruit_ImageReader.h>
#include "logic_evaluator.h"
#include <Adafruit_Neopixel.h>
#include "logic_wire_lights.h"
#include "puzzle_manager.h"
#include "InputManager.h"

#define TEST_WRITE_TO_CARD false
#define TEST_WRITE_TO_CARD_NAME "MISSING-NO"
/*
Curr Test Cards:
  - TEMP_CONTROL
  - AIR_SCRUBBERS

*/

#define LED_COUNT 20

extern SPIClass mainBoardSpi;
extern SdFat mainBoardSD;
Adafruit_ImageReader reader(mainBoardSD);

Adafruit_ST7796S display1(&mainBoardSpi, MAIN_BOARD_LCD_1_CS, MAIN_BOARD_LCD_DC, MAIN_BOARD_LCD_RESET);
Adafruit_ST7796S display2(&mainBoardSpi, MAIN_BOARD_LCD_2_CS, MAIN_BOARD_LCD_DC, MAIN_BOARD_LCD_RESET);
// Adafruit_ILI9341 disp(&mainBoardSpi, MAIN_BOARD_LCD_2_CS, MAIN_BOARD_LCD_DC, MAIN_BOARD_LCD_RESET);

EthernetClass ethMain;

Adafruit_NeoPixel mainStrip = Adafruit_NeoPixel(LOGIC_WIRE_NUM_LEDS, MAIN_BOARD_WS2812_PIN, NEO_RGB+NEO_KHZ800); 

static TimerHandle_t logicGridTimer;
static TimerHandle_t inputTimer;
static TimerHandle_t ISOCardTimer;
volatile bool shouldUpdateGrid = false;
volatile bool shouldUpdateButtons = false;
volatile bool shouldCheckInputs = false;
volatile bool shouldCheckISOCards = false;


void setLogicGateUpdateFlag(TimerHandle_t handle);
void setInputUpdateFlag(TimerHandle_t handle);
void setISOUpdateFlag(TimerHandle_t handle);


void setupGeneralLightStrips();


void setup() {
  MainBoardStart(true);
  Serial.println("Logic Re-Initialization Panel");

  initInputs();

  setupGeneralLightStrips();

  initISOCards(NUM_ISO_CARDS_LOGIC_PANEL, &mainStrip);

  initPuzzleManager(&mainStrip, 0, &display2);

  pinMode(MAIN_BOARD_LCD_1_CS, INPUT_PULLUP);
  pinMode(MAIN_BOARD_LCD_2_CS, INPUT_PULLUP);

  analogWrite(MAIN_BOARD_LCD_BRIGHTNESS, 0xFF);
  analogWrite(MAIN_BOARD_LCD_RESET, 0);
  delay(10);
  analogWrite(MAIN_BOARD_LCD_RESET, 0xFF);
  display2.init(LCD_H, LCD_W, 0, 0, ST7796S_BGR);
  display2.invertDisplay(true);
  display2.setRotation(LCD_ROTATION);
  display2.fillScreen(0);
  Adafruit_Image image;
  ImageReturnCode readLogoFromFile = reader.loadBMP("/Pictures/spaceship.bmp", image);
  if(readLogoFromFile == IMAGE_SUCCESS){
    image.draw(display2, 0, 0);
  } else{
    display2.setTextSize(3);
    display2.print("Critical Error! Logic Re-Initializer Failed To start!");
  }

  logicGridTimer = xTimerCreate("Shot Reload", pdMS_TO_TICKS(500), pdTRUE, NULL, setLogicGateUpdateFlag);

  if(logicGridTimer == NULL){
    Serial.println("Failed to start Update Grid ISR!");
  } else{
    xTimerStart(logicGridTimer, 0);
  }

  inputTimer = xTimerCreate("Shot Reload", pdMS_TO_TICKS(10), pdTRUE, NULL, setInputUpdateFlag);

  if(inputTimer == NULL){
    Serial.println("Failed to start Update Grid ISR!");
  } else{
    xTimerStart(inputTimer, 0);
  }

  ISOCardTimer = xTimerCreate("Shot Reload", pdMS_TO_TICKS(150), pdTRUE, NULL, setISOUpdateFlag);

  if(ISOCardTimer == NULL){
    Serial.println("Failed to start Update Grid ISR!");
  } else{
    xTimerStart(ISOCardTimer, 0);
  }

  #if TEST_WRITE_TO_CARD
  ISO_CARD freshCardToWrite;
  freshCardToWrite.slotID = LOGIC_GATE_SLOT_NUMBER;
  char* stringName = TEST_WRITE_TO_CARD_NAME;
  memcpy(freshCardToWrite.payload, stringName, strlen(stringName));
  freshCardToWrite.payloadLen = strlen(stringName);
  Serial.print("Payload Len: ");
  Serial.println(freshCardToWrite.payloadLen);

  while(!attemptToWriteToCard(freshCardToWrite)){
    Serial.println("Write to card failed, trying again");
    delay(500);
  }
  #endif

  // setPuzzleDemoMode(true);

  Serial.print("Initialization Complete @");
  Serial.print(millis());
  Serial.println("ms");
}


void loop() {
  if(shouldUpdateGrid){
    shouldUpdateGrid = false;
    tickPuzzleManager();
  }
  if(shouldCheckInputs){
    shouldCheckInputs = false;
    tickInputs();
  }
  if(shouldCheckISOCards){
    shouldCheckISOCards = false;
    tickParseLogicCards();
  }
}

void setLogicGateUpdateFlag(TimerHandle_t handle){
  shouldUpdateGrid = true;
}


void setInputUpdateFlag(TimerHandle_t handle){
  shouldCheckInputs = true;
}


void setISOUpdateFlag(TimerHandle_t handle){
  shouldCheckISOCards = true;
}


void setupGeneralLightStrips(){
  mainStrip.updateLength(LOGIC_WIRE_NUM_LEDS + ISO_CARDS_NUM_LEDS_PER_CARD);
  mainStrip.begin();
  mainStrip.setBrightness(LOGIC_WIRE_BRIGHTNESS);
  mainStrip.fill(mainStrip.Color(255,0,0));
  mainStrip.show();
  delay(250);
  mainStrip.fill(mainStrip.Color(0,255,0));
  mainStrip.show();
  delay(250);
  mainStrip.fill(mainStrip.Color(0,0,255));
  mainStrip.show();
  delay(250);
  mainStrip.clear();
  mainStrip.show();
}

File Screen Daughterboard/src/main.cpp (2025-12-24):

#include <Arduino.h>
#include <SPI.h>
#include <SPISlave.h>
#include <spiCommands.h>

// spi 0 is master, spi 1 is slave
#define MISO 15
#define MOSI 12
#define SCK 14
#define MASTER_CS 5
#define MISO1 0
#define MOSI1 3
#define SCK1 2
#define SPI_SLAVE_CS 13

#define SPI_FREQUENCIES (1 * 1000 * 1000)
#define RX_BUFFER_SIZE 256
#define TX_BUFFER_SIZE 256

char msg[RX_BUFFER_SIZE];
char backtalk[TX_BUFFER_SIZE];

SPISettings spisettings(SPI_FREQUENCIES, MSBFIRST, SPI_MODE0);

void setup() {
  delay(4000);
  SPI.setRX(MISO1);
  SPI.setTX(MOSI1);
  SPI.setSCK(SCK1);
  SPI.setCS(MASTER_CS);
  SPI.begin(true);

  Serial.println("Master Started");
  
}

void loop() {
  delay(5000);
  SPI.beginTransaction(spisettings);
  sprintf(msg + 1, "Current Millis: %ld\r\n", millis());
  Serial.print("Transmitting: ");
  Serial.print(msg + 1);
  // msg[0] = SEND_STRING;
  // msg[1] = strlen(msg + 1);
  msg[0] = 255;
  Serial.printf("Length of transmission: %d\n", strlen(msg + 1) + 1);
  SPI.transferAsync(msg, backtalk, 256);
  // msg[0] = FINISH_STRING;
  // SPI.transferAsync(msg, backtalk, 1);
  while (!SPI.finishedAsync());
  SPI.endTransaction();
}





volatile bool newDataReceived = false;
int8_t rxBuffer[32];
int recvIdx = 0;
void recvCallback(uint8_t *data, size_t len){
  memcpy(rxBuffer + recvIdx, data, len);
  recvIdx += len;
  if (recvIdx >= sizeof(rxBuffer)) {
    newDataReceived = true;
    recvIdx = 0;
  }
}

int8_t txBuffer[TX_BUFFER_SIZE];
size_t txSize = 1;
void sentCallback(){
  SPISlave1.setData((uint8_t*)txBuffer, txSize);
}


void setup1() {

  SPISlave1.setRX(MOSI);
  Serial.println("RX");
  SPISlave1.setTX(MISO);
  Serial.println("TX");
  SPISlave1.setCS(SPI_SLAVE_CS);
  Serial.println("CS");
  SPISlave1.setSCK(SCK);
  Serial.println("Set Pins");

  sentCallback();
  recvCallback(0,0);
  Serial.println("Called Back");

  SPISlave1.onDataRecv(recvCallback);
  SPISlave1.onDataSent(sentCallback);
  Serial.println("Assigned callbacks");
  SPISlave1.begin(spisettings);


  delay(3000);
  Serial.println("S-INFO: SPISlave1 started");
}

void loop1() {
  if(newDataReceived){
    Serial.print("Master Sent: ");
    Serial.println((char*) rxBuffer);
    newDataReceived = false;
  }
}

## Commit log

2025-09-20 Initial Move-Over from susbystem documentation
    This was all moved over from the Subsystem Documentation repository, to its own new repository
    [And Gate.stl, Back Body.stl, Card Bare Minimum.stl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]
2025-09-26 moved 3d models
    [Card Bare Minimum.stl, Card Test.stl, Isolinear Chip back V2.stl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]
2025-09-26 Move STL files and add project README
    Moved STL files to the '3D Models/Apollo Gauge' directory for better organization. Added a README.md describing the Logic Initialization Panel project, its purpose, and educational goals.
    [Back Body.stl, Gauge Drum.stl]
2025-10-08 Add STEP models for headers and display
    Added 3D STEP files for 14 pin female header, 4 pin female header, and ST7796S Display v7. Included a readme and terms of use for the 14 pin header model.
    [14 pin female header.stp, 4 pin female header.step, ST7796S Display v7.step]
2025-10-17 Made the LCD daughter board
    [LCD_Daughter.kicad_pcb, LCD_Daughter.kicad_sch, LCD_Daughter.step]
2025-10-24 Renamed SPI busses to match RPI's names. Fixed code to use the correct SPI busses.
    [LCD_Daughter.kicad_pcb, LCD_Daughter.kicad_sch]
2025-12-24 First working prototype
    Only reads the first 4 ports but otherwise works
2025-12-24 Improve gate status serial output formatting
    Updated the loop to print gate statuses in a 4x4 grid format, providing clearer visualization of current gate states for debugging.
2025-12-28 Created PCB for the LEDs on the Logic Panel
    [B3B-XH-A.STEP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]
2025-12-28 Add Isolinear Chips NFC 3D model files
    Added new 3D model files for the Isolinear Chips NFC project, including Card Holder, Clip, Iso Card Body, Iso Card Diffuser, and a print profile. These files support the creation and printing of NFC-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
    [Card Holder.stl, Clip.stl, Iso Card Body.stl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]
2025-12-29 added logic board source file
    [Iso Card Body V2.stl, Iso Card Diffuser V2.stl]
2025-12-31 Add ISO card NFC support and unit tests
    Introduced isoCards library for handling ISO card NFC readers, including initialization, card management, and serialization. Updated platformio.ini to include Adafruit PN532 dependency. Added unit tests for card serialization. Minor fix in logic_evaluator.cpp to correct header include.
    [main.cpp]
2026-01-01 St7796S code, however CS is not asserting for some reason, Am going to try other library after this
    Integrated Adafruit_ST7796S library for dual LCD support, initialized two ST7796S displays, and added related pin definitions. Reduced SPI frequency from 80MHz to 30MHz for compatibility. Updated dep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
2026-01-09 Kicad LCD daughterboard
2026-01-09 Started work on logic wire lights (unfinished commit)
2026-05-31 NFC tag reader operational and Button holder PCB files
    Got ISO cards reading and writing
    Uploaded PCB for ISO card reader LEDs
    [B3B-XH-A.STEP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]
2026-07-03 Checks for valid solution
    - Iso cards now light up
    - Input buttons now work
    - Checks for valid puzzle solutions
    [Logic Test Package.3mf]

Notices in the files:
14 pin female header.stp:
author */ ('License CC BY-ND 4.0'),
